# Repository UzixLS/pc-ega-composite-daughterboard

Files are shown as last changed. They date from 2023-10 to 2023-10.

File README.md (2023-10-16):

## EGA composite daughterboard
Daughterboard for EGA feature connector, providing CVBS composite video encoder. With this board you can connect your EGA videocard to TV using two RCA jacks, which is usually unused on most EGA cards. One jack is feed by NTSC encoder, other by PAL.

For proper work you must set card to CGA-compatible mode. If card tries to output EGA-Hi-Res modes, composite output will be unsupported by most monitors.

Please note that CGA composite colors will not display properly.

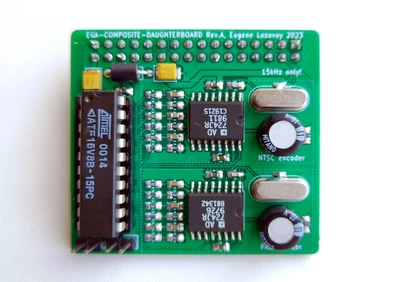
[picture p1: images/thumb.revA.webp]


### Jumper setting
* JP1 is not installed - RGBI color mode
* JP1 installed        - RrGgBb color mode (just for testing)
* JP2 is not installed - separate sync for AD724
* JP2 installed        - composite sync for AD724 (just for testing)

Normally both jumper shouldn't be installed.

### Changelog
* Rev.A - initial release
* Rev.A1 - add option to use ISA clock for NTSC encoder; improve power circuit

### Related projects
- https://github.com/monotech/EGA-Mono-Composite-Coverter
- https://github.com/hkzlab/ISA_EGA_CHIPS

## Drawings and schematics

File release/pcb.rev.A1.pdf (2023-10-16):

1 | 2 | 3 | 4 | 5 | 6

A

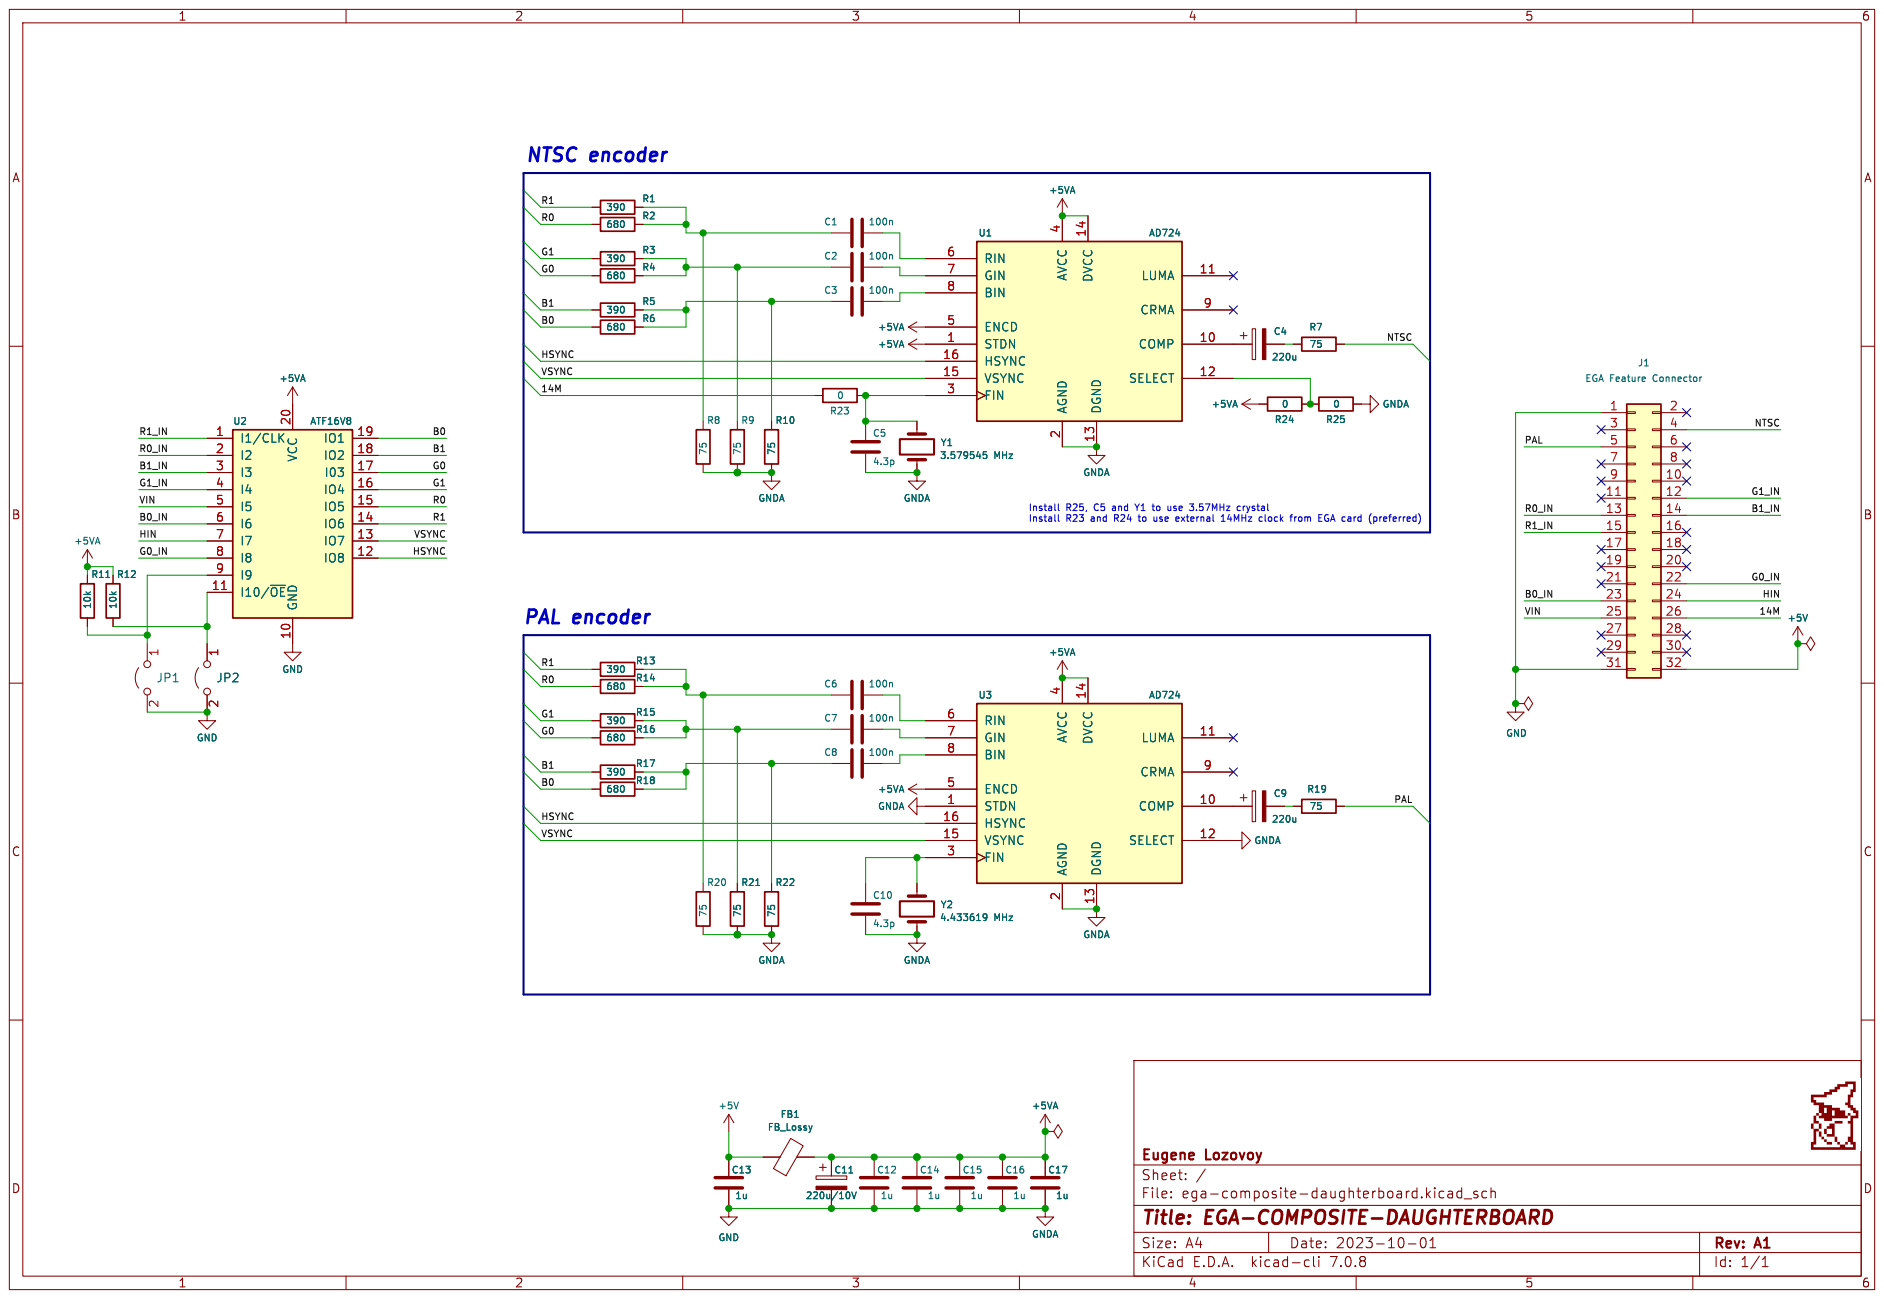
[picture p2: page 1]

4 ENCD 5 RIN 6 GIN 7 BIN 8 CRMA 9 U1 AD724 C4

4 ENCD 5 RIN 6 GIN 7 BIN 8 CRMA 9

4 ENCD 5 RIN 6 GIN 7 BIN 8 CRMA 9 U3 AD724

Id: 1/1 Title: EGA-COMPOSITE-DAUGHTERBOARD

A

A

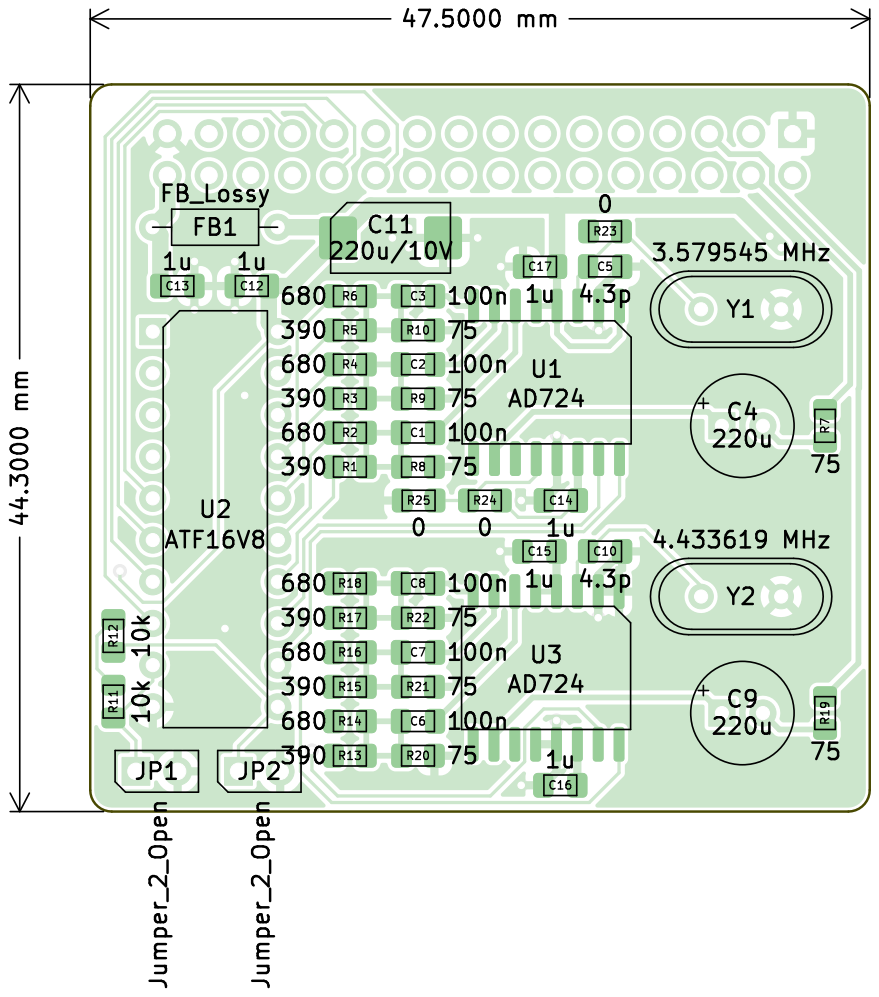
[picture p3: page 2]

Id: 1/1 Title: EGA-COMPOSITE-DAUGHTERBOARD

A

A

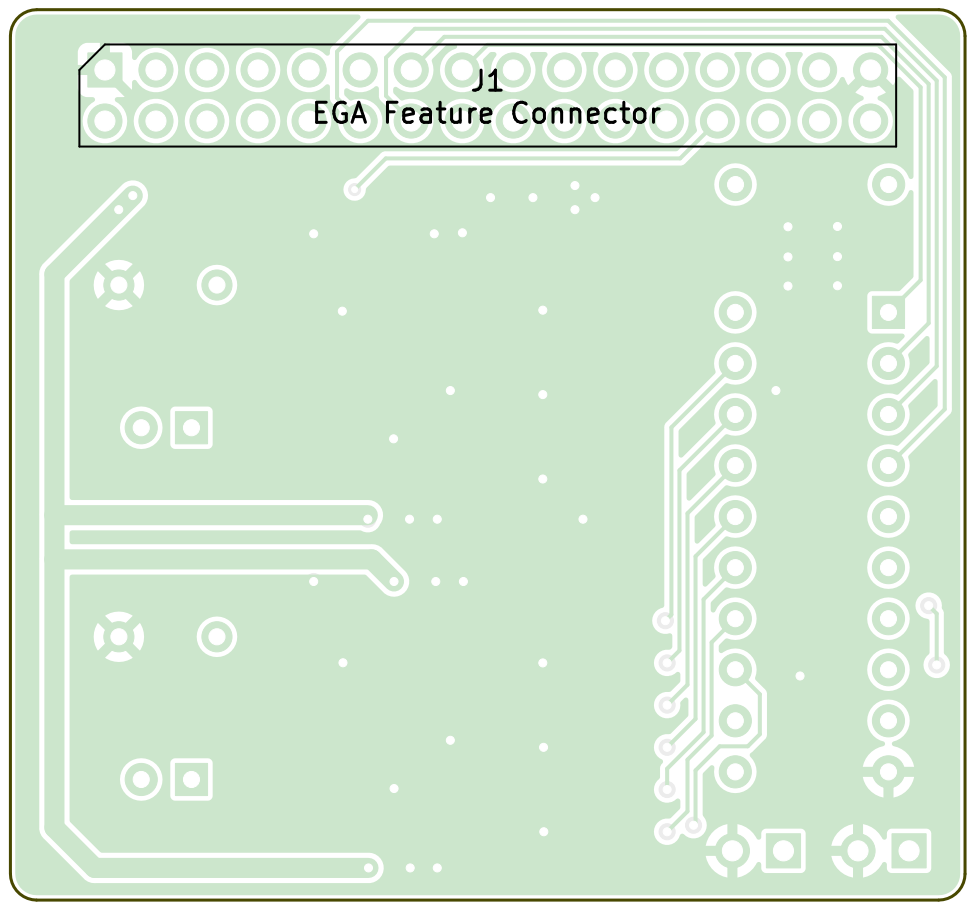
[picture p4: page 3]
D Date: 2023-10-01; ${KICAD_VERSION} Size: A4; Rev: A1; File: ega-composite-daughterboard.kicad_pcb Sheet: Eugene; Lozovoy

Id: 1/1 Title: EGA-COMPOSITE-DAUGHTERBOARD

# Bill Of Materials

References | | | Value | Footprint | Qty
C1 C2 C3 C6 C7 C8 | 100n | Capacitor_SMD:C_0805_2012Metric_Pad1.1 8x1.45mm_HandSolder | 6
C11 | 220u/10V | Capacitor_Tantalum_SMD:CP_EIA-7343-31_ Kemet-D_Pad2.25x2.55mm_HandSolder | 1
C12 C13 C14 C15 C16 C17 | 1u | Capacitor_SMD:C_0805_2012Metric_Pad1.1 8x1.45mm_HandSolder | 6
C4 C9 | 220u | Capacitor_THT:CP_Radial_D6.3mm_P2.50m m | 2
C10 C5 | 4.3p | Capacitor_SMD:C_0805_2012Metric_Pad1.1 8x1.45mm_HandSolder | 2
FB1 | FB_Lossy | Inductor_THT:L_Axial_L5.3mm_D2.2mm_P7. 62mm_Horizontal_Vishay_IM-1 | 1
J1 | EGA Feature Connector | Connector_PinHeader_2.54mm:PinHeader_2 x16_P2.54mm_Vertical | 1
JP1 JP2 | Jumper_2_Open | Connector_PinHeader_2.54mm:PinHeader_1 x02_P2.54mm_Vertical | 2
R1 R13 R15 R17 R3 R5 | 390 | Resistor_SMD:R_0805_2012Metric_Pad1.20 x1.40mm_HandSolder | 6
R11 R12 | 10k | Resistor_SMD:R_0805_2012Metric_Pad1.20 x1.40mm_HandSolder | 2
R14 R16 R18 R2 R4 R6 | 680 | Resistor_SMD:R_0805_2012Metric_Pad1.20 x1.40mm_HandSolder | 6
R23 R24 R25 | 0 | Resistor_SMD:R_0805_2012Metric_Pad1.20 x1.40mm_HandSolder | 3
R10 R19 R20 R21 R22 R7 R8 R9 | 75 | Resistor_SMD:R_0805_2012Metric_Pad1.20 x1.40mm_HandSolder | 8
U1 U3 | AD724 | Package_SO:SOIC-16W_7.5x10.3mm_P1.27 mm | 2
U2 | ATF16V8 | Package_DIP:DIP-20_W7.62mm | 1
Y1 | 3.579545 MHz | Crystal:Crystal_HC49-4H_Vertical | 1
Y2 | 4.433619 MHz | Crystal:Crystal_HC49-4H_Vertical | 1

# ega-composite-daughterboard rev.A1 BOM page 1/1

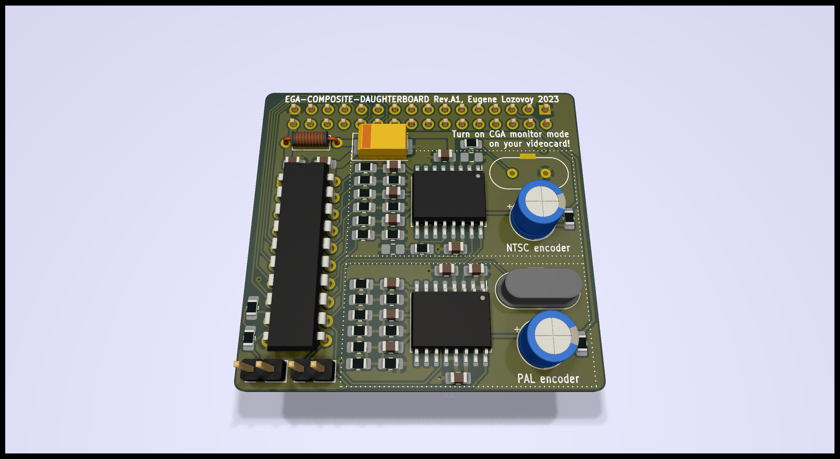
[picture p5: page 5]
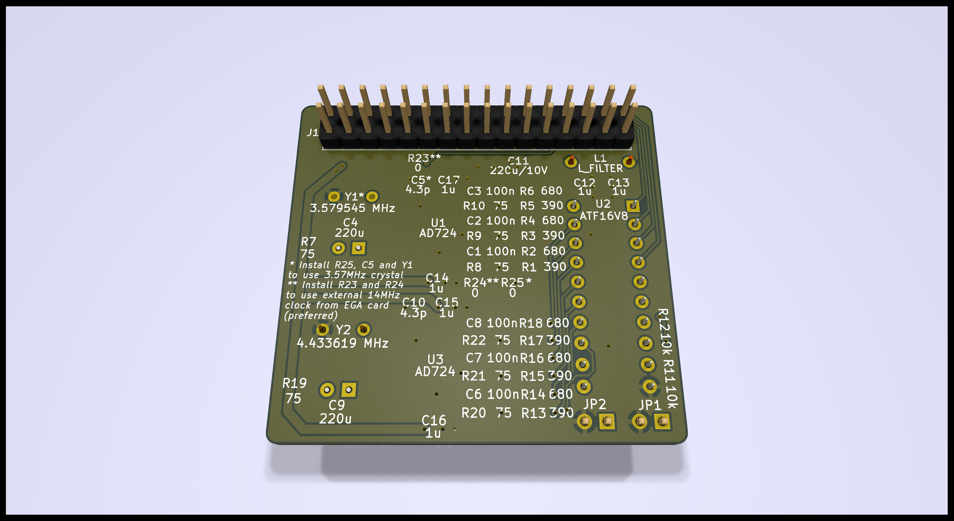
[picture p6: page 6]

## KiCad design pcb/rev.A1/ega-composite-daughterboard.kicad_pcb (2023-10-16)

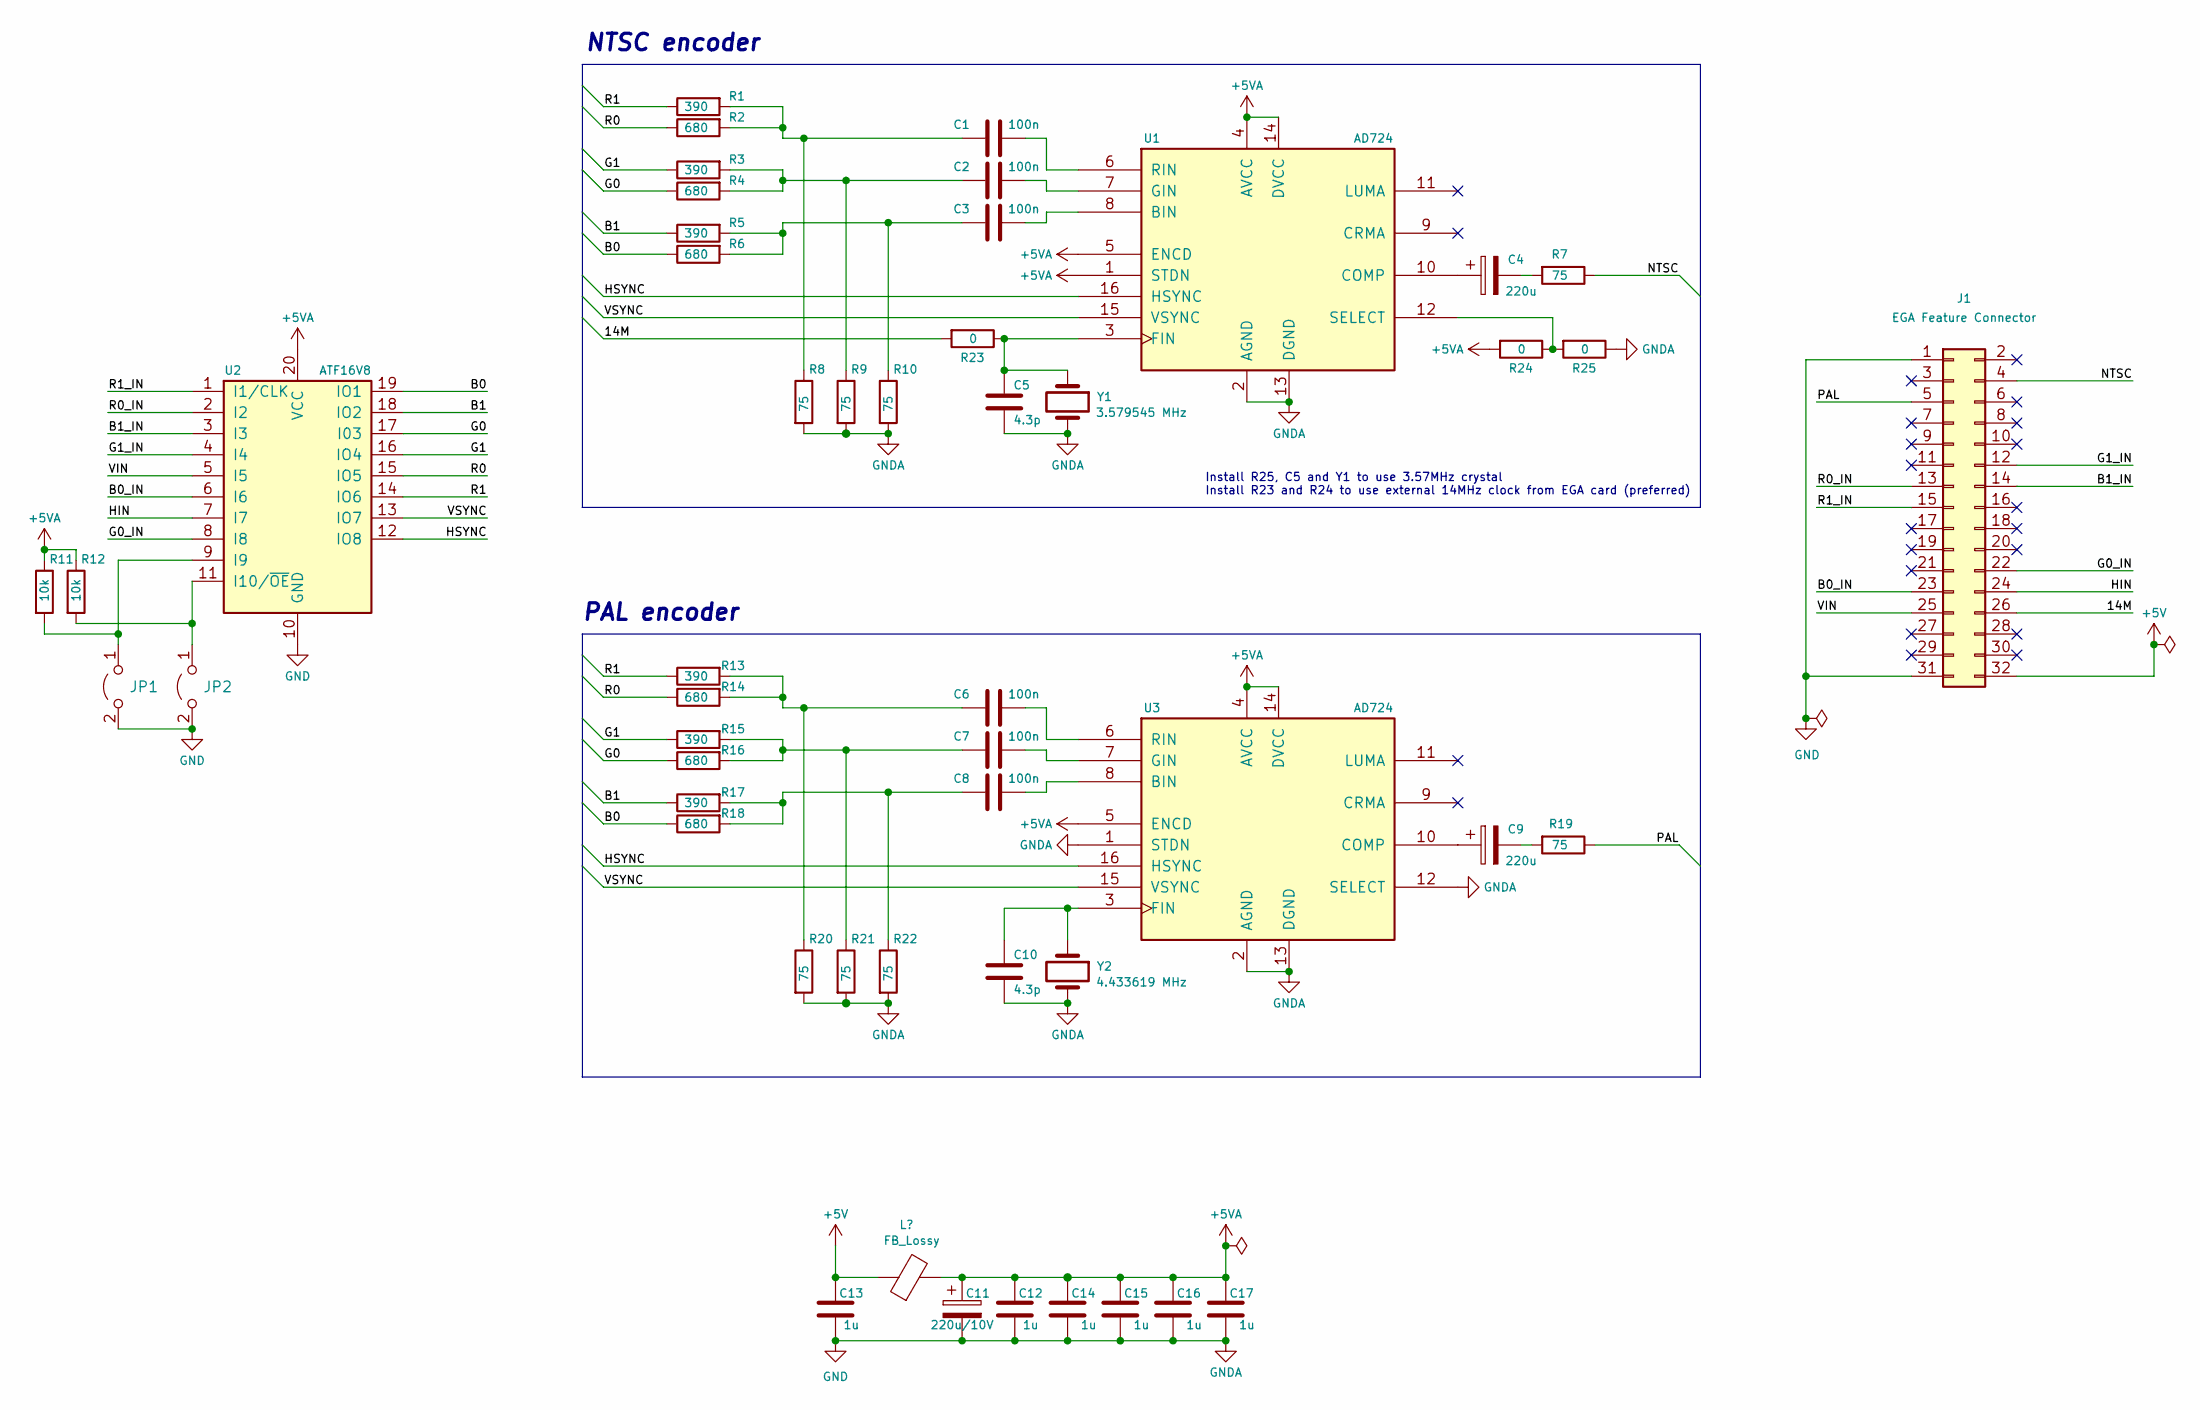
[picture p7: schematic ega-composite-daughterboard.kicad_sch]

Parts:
C1, C2, C3, C6, C7, C8: 100n; C_0805_2012Metric_Pad1.18x1.45mm_HandSolder
C4, C9: 220u; CP_Radial_D6.3mm_P2.50mm
C5, C10: 4.3p; C_0805_2012Metric_Pad1.18x1.45mm_HandSolder
C11: 220u/10V; CP_EIA-7343-31_Kemet-D_Pad2.25x2.55mm_HandSolder
C12, C13, C14, C15, C16, C17: 1u; C_0805_2012Metric_Pad1.18x1.45mm_HandSolder
FB1: FB_Lossy; L_Axial_L5.3mm_D2.2mm_P7.62mm_Horizontal_Vishay_IM-1
J1: EGA Feature Connector; PinHeader_2x16_P2.54mm_Vertical
JP1, JP2: Jumper_2_Open; PinHeader_1x02_P2.54mm_Vertical
R1, R3, R5, R13, R15, R17: 390; R_0805_2012Metric_Pad1.20x1.40mm_HandSolder
R2, R4, R6, R14, R16, R18: 680; R_0805_2012Metric_Pad1.20x1.40mm_HandSolder
R7, R8, R9, R10, R19, R20, R21, R22: 75; R_0805_2012Metric_Pad1.20x1.40mm_HandSolder
R11, R12: 10k; R_0805_2012Metric_Pad1.20x1.40mm_HandSolder
R23, R24, R25: 0; R_0805_2012Metric_Pad1.20x1.40mm_HandSolder
U1, U3: AD724; SOIC-16W_7.5x10.3mm_P1.27mm
U2: ATF16V8; DIP-20_W7.62mm
Y1: 3.579545 MHz; Crystal_HC49-4H_Vertical
Y2: 4.433619 MHz; Crystal_HC49-4H_Vertical

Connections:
+5V: C13.2, FB1.1, J1.32
+5VA: C11.1, C12.2, C14.2, C15.2, C16.2, C17.2, FB1.2, R11.1, R12.1, R24.2, U1.1 (STDN), U1.4 (AVCC), U1.5 (ENCD), U1.14 (DVCC), U2.20 (VCC), U3.4 (AVCC), U3.5 (ENCD), U3.14 (DVCC)
/14M: J1.26, R23.2
/B0: R6.1, R18.1, U2.19 (IO1)
/B0_IN: J1.23, U2.6 (I6)
/B1: R5.1, R17.1, U2.18 (IO2)
/B1_IN: J1.14, U2.3 (I3)
/G0: R4.1, R16.1, U2.17 (I03)
/G0_IN: J1.22, U2.8 (I8)
/G1: R3.1, R15.1, U2.16 (IO4)
/G1_IN: J1.12, U2.4 (I4)
/HIN: J1.24, U2.7 (I7)
/HSYNC: U1.16 (HSYNC), U2.12 (IO8), U3.16 (HSYNC)
/NTSC: J1.4, R7.1
/PAL: J1.5, R19.1
/R0: R2.1, R14.1, U2.15 (IO5)
/R0_IN: J1.13, U2.2 (I2)
/R1: R1.1, R13.1, U2.14 (IO6)
/R1_IN: J1.15, U2.1 (I1/CLK)
/VIN: J1.25, U2.5 (I5)
/VSYNC: U1.15 (VSYNC), U2.13 (IO7), U3.15 (VSYNC)
GND: C5.2, C10.2, C11.2, C12.1, C13.1, C14.1, C15.1, C16.1, C17.1, J1.1, J1.31, JP1.2 (B), JP2.2 (B), R8.2, R9.2, R10.2, R20.2, R21.2, R22.2, R25.1, U1.2 (AGND), U1.13 (DGND), U2.10 (GND), U3.1 (STDN), U3.2 (AGND), U3.12 (SELECT), U3.13 (DGND), Y1.2, Y2.2
unnamed: C1.2, R1.2, R2.2, R8.1
unnamed: C2.2, R3.2, R4.2, R9.1
unnamed: C3.2, R5.2, R6.2, R10.1
unnamed: C4.2, R7.2
unnamed: C6.2, R13.2, R14.2, R20.1
unnamed: C7.2, R15.2, R16.2, R21.1
unnamed: C8.2, R17.2, R18.2, R22.1
unnamed: C9.2, R19.2
unnamed: JP1.1 (A), R11.2, U2.9 (I9)
unnamed: JP2.1 (A), R12.2, U2.11 (I10/~OE)
unnamed: C3.1, U1.8 (BIN)
unnamed: C4.1, U1.10 (COMP)
unnamed: C5.1, R23.1, U1.3 (FIN), Y1.1
unnamed: C2.1, U1.7 (GIN)
unnamed: C1.1, U1.6 (RIN)
unnamed: R24.1, R25.2, U1.12 (SELECT)
unnamed: C8.1, U3.8 (BIN)
unnamed: C9.1, U3.10 (COMP)
unnamed: C10.1, U3.3 (FIN), Y2.1
unnamed: C7.1, U3.7 (GIN)
unnamed: C6.1, U3.6 (RIN)

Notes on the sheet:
PAL encoder
NTSC encoder
Install R25, C5 and Y1 to use 3.57MHz crystal Install R23 and R24 to use external 14MHz clock from EGA card (preferred)

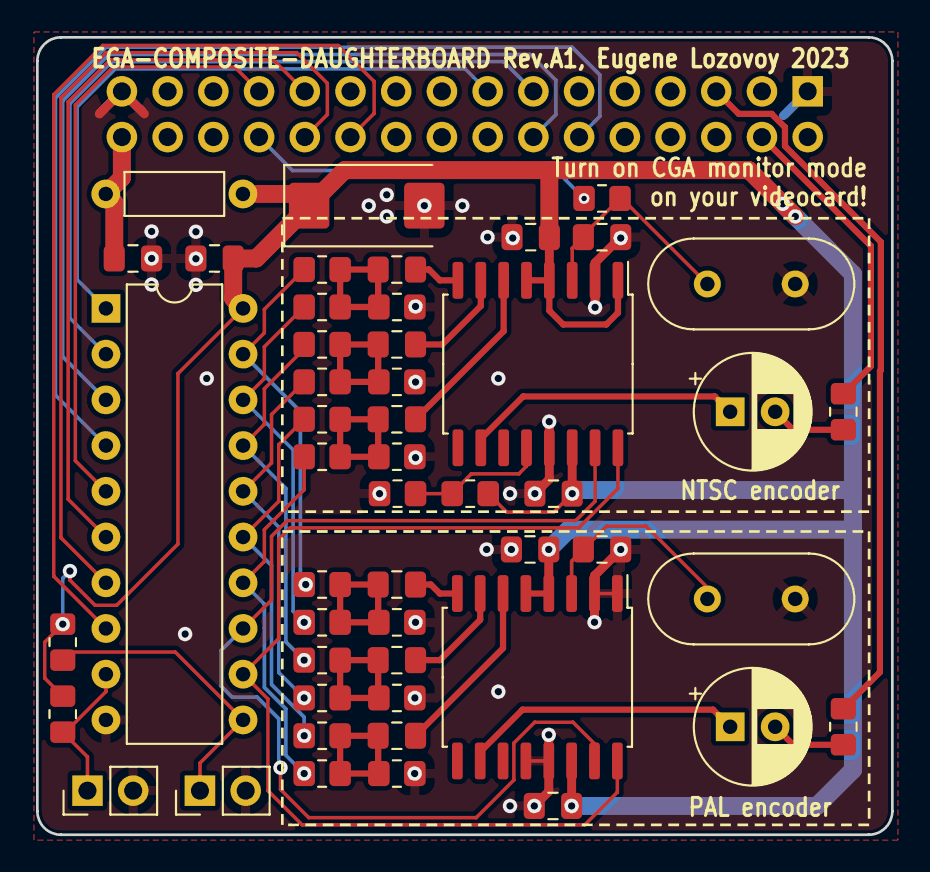
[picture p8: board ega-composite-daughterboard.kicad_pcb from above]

Board: 2 copper layers, 47.5 x 44.3 mm, 51 parts (1 on the bottom side), 43 nets.

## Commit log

2023-06-21 wip pcb rev.A
    [pc-ega-composite-daughterboard.kicad_pcb, pc-ega-composite-daughterboard.kicad_sch]
2023-10-16 rename project files
    [ega-composite-daughterboard.kicad_pcb, ega-composite-daughterboard.kicad_sch, pc-ega-composite-daughterboard.kicad_pcb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]
2023-10-16 add pcb rev.A1 files
    [ega-composite-daughterboard.kicad_pcb, ega-composite-daughterboard.kicad_sch]
